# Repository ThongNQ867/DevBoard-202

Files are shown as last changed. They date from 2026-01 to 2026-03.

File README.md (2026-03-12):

# DevBoard202
This is a dev board that runs with the RP2040 but structured more simple than Pi Pico. The schematic is inspired by the document "Hardware design with RP2040", the PCB is made with the tutorial from @KaiPereira.
The reason I do this project is to understand more about how capacitors, resistors are used with components like MCU, oscillator, USB ports. Moreover, design a development board provide more control over how  I can use the MCU, in which I remove some functionalities from the Pi Pico to make this board simple and easier to use. 

Using instruction:
Using this development board is similar to any other development board. We can just plug wires to GPIO pins to use. The usage of GPIO pins can be find on the datasheet of Raspberry Pi Pico or the RP2040 itself. This dev board can be used with external power source, and to do so, we can wire a 5V power source to the VBus or VSYS pins.

While there is a tutorial from Blueprint, I think it is better to fact check stuffs again and get understand more clearly about how to set up the value for resistors and capacitors by myself from these 2 links:
RP2040 datasheet
https://pip-assets.raspberrypi.com/categories/814-rp2040/documents/RP-008371-DS-1-rp2040-datasheet.pdf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

Hardware design with rp2040
https://pip-assets.raspberrypi.com/categories/814-rp2040/documents/RP-008279-DS-1-hardware-design-with-rp2040.pdf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

Pi Pico Datasheet
https://pip-assets.raspberrypi.com/categories/610-raspberry-pi-pico/documents/RP-008307-DS-1-pico-datasheet.pdf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

Here is the result:
3D model: 

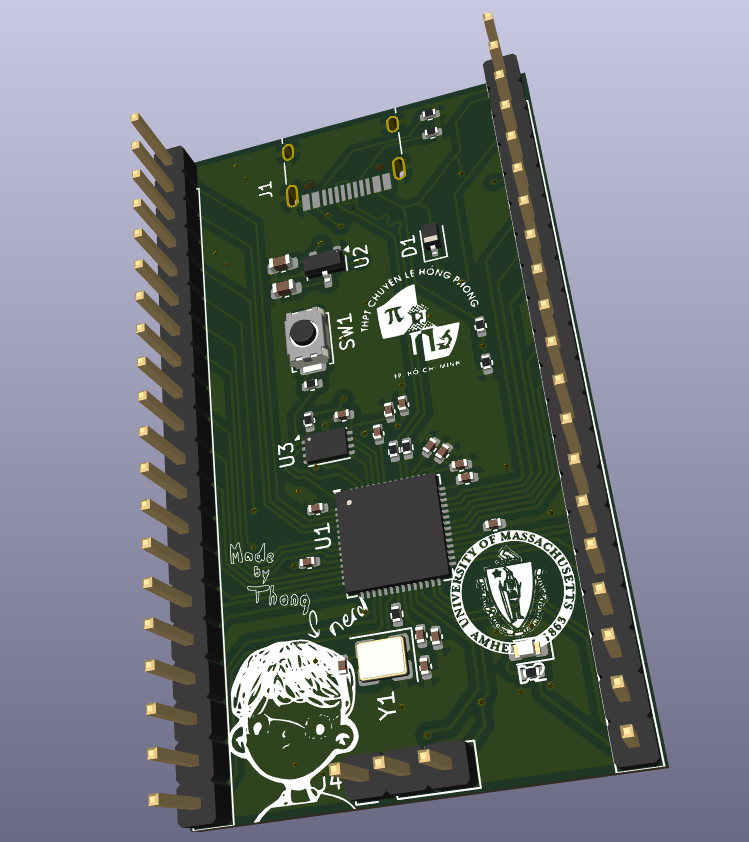
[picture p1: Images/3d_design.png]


Schematic: 

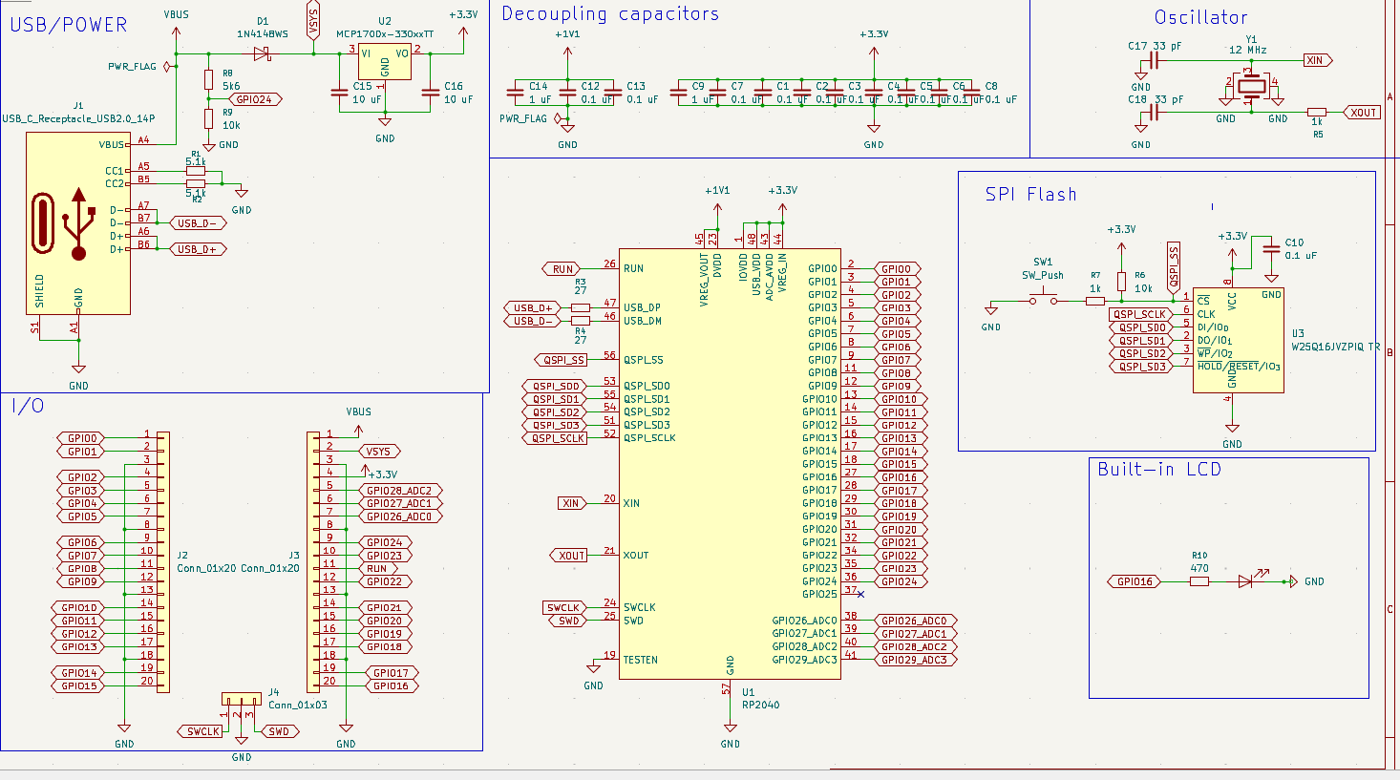
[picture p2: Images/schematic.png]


PCB: 

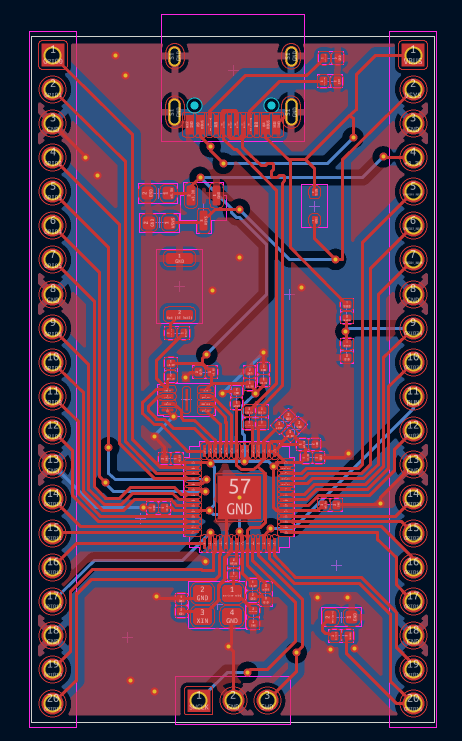
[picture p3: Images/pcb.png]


First, lets start of with setting up the decoupling capacitors. From the tutorial, it is recommended to used 1 capacitors per powerline so I just follow it. However, I found it a bit troublesome to actually know which pin is a powerline as I'm not very used to reading datasheets. Before this, I had always connect the pins to the capacitor (just as the datasheets often describe), making the schematic super hard to read. However, from the tutorial, I learnt that I can connect them seperately, making the schematic much more easier to read, and also solving the problem that the symbol of rp2040 on kicad doesnt shows all the power pins. 

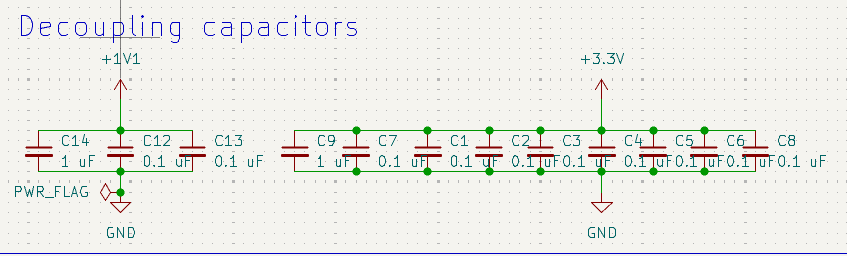
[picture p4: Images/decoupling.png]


Next is the powerline. Though it looks simple, it actually took me some time to actually figure out how the powerline, VSYS and VBUS works as I was trying to make my devboard be able to use an external power source. I added a VSYS pin which include the use of a Schottky diode between the VBUS and VSYS so that I can power it by an external power source. I found it quite challenging to understand how the USB host mode work but I think powering the external power source to the VBUS would probably be fine. Also because of powering externally to VSYS, I also pull VBUS down if its not connected to power source with 2 resistors to GND. After that, I also decided to wire the VBUS to a GPIO pin to detect if the board is using external power source

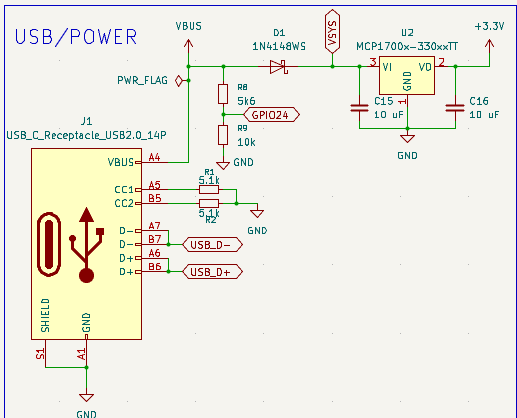
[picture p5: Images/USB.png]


SPI flash, built-in LED and oscillator is pretty straight forward, but I did learn so much on how to calculate the resistor for the oscillator.

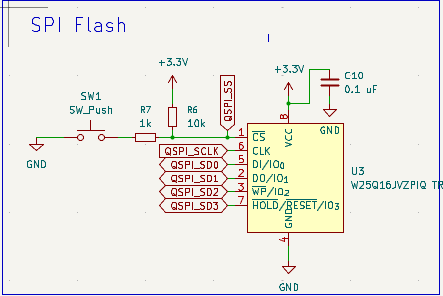
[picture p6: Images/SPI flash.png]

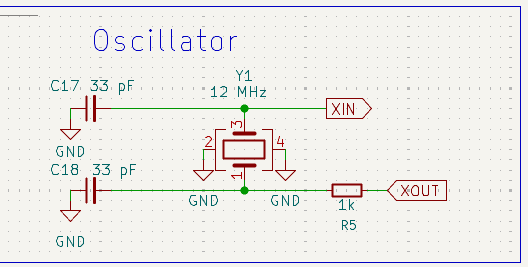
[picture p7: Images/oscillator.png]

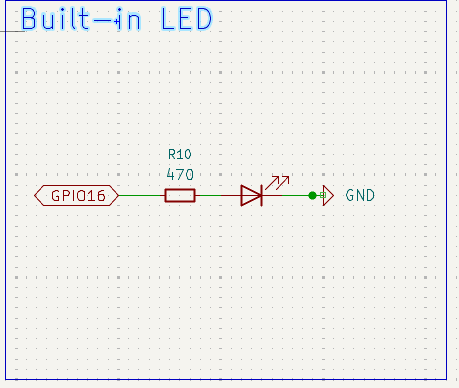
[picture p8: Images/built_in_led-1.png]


For me, PCB routing is the most problematic part of this project, partly because I'm new to KiCAD, partly because of the enormous diode (which I have changed to a more cost effective and 10 times smaller version). I started trying to make a PCB with the size of a Pi Pico but ended up increase the width to make the wiring easier 



This project has taught me a lot on how to use KiCAD and choose componets to print for my PCB. 

BOM: 
| Name | Comment | Designator | Footprint | JLCPCB Part # | Quantity | Links |
|---|---|---|---|---|---|---|
| CL10A106MA8NRNC | 10uF | C15,C16 | C_0603_1608Metric | C96446 | 2 | https://jlcpcb.com/partdetail/97651-CL10A106MA8NRNC/C96446 |
| CL05A105KA5NQNC | 1uF | C9,C14 | C_0402_1005Metric | C52923 | 2 | https://jlcpcb.com/partdetail/53938-CL05A105KA5NQNC/C52923 |
| MCP1700T-3302E/TT LDO | MCP1700x-330xxTT | U2 | SOT-23 | C39051 | 1 | https://jlcpcb.com/partdetail/MicrochipTech-MCP1700T_3302ETT/C39051 |
| 0402CG330J500NT | 33pF | C18,C17 | C_0402_1005Metric | C1562 | 2 | https://jlcpcb.com/partdetail/1914-0402CG330J500NT/C1562 |
| 0402WGF1001TCE | 1k | R7,R5 | R_0402_1005Metric | C11702 | 2 | https://jlcpcb.com/partdetail/12256-0402WGF1001TCE/C11702 |
| RCT0227RJLF | 27 | R3,R4 | R_0402_1005Metric | C174257 | 2 | https://jlcpcb.com/partdetail/HKR_Hong_Kong_Resistors-RCT0227RJLF/C174257 |
| 0402WGF5101TCE | 5.1k | R2,R1 | R_0402_1005Metric | C25905 | 2 | https://jlcpcb.com/partdetail/26648-0402WGF5101TCE/C25905 |
| X322512MSB4SI oscillator | 12MHz | Y1 | Crystal_SMD_3225-4Pin_3.2x2.5mm | C9002 | 1 | https://jlcpcb.com/partdetail/YXC_CrystalOscillators-X322512MSB4SI/C9002 |
| 0402WGF5601TCE | 5k6 | R8 | R_0402_1005Metric | C25908 | 1 | https://jlcpcb.com/partdetail/26651-0402WGF5601TCE/C25908 |
| 1N4148WS diode | 1N4148WS | D1 | D_SOD-323 | C2128 | 1 | https://jlcpcb.com/partdetail/2485-1N4148WS/C2128 |
| 0402WGF470JTCE | 470 | R10 | R_0402_1005Metric | C25118 | 1 | https://jlcpcb.com/partdetail/25861-0402WGF470JTCE/C25118 |
| RP2040 | RP2040 | U1 | QFN-56-1EP_7x7mm_P0.4mm_EP3.2x3.2mm | C2040 | 1 | https://jlcpcb.com/partdetail/RaspberryPi-RP2040/C2040 |
| CL05B104KO5NNNC | 100nF | C8,C7,C13,C5,C12,C1,C2,C6,C4,C10,C3 | C_0402_1005Metric | C1525 | 11 | https://jlcpcb.com/partdetail/1877-CL05B104KO5NNNC/C1525 |
| W25Q16JVUXIQ Flash | W25Q16JVZPIQTR | U3 | Winbond_USON-8-1EP_3x2mm_P0.5mm_EP0.2x1.6mm | C2843335 | 1 | https://jlcpcb.com/partdetail/WinbondElec-W25Q16JVUXIQ/C2843335 |
| KT-0603R LED | LED | D2 | LED_0603_1608Metric | C2286 | 1 | https://jlcpcb.com/partdetail/Hubei_KENTOElec-KT0603R/C2286 |
| 402WGF1002TC | 10k | R6,R9 | R_0402_1005Metric | C25744 | 2 | https://jlcpcb.com/partdetail/26487-0402WGF1002TCE/C25744 |
| TYPE-C-31-M-12 USB-C port | USB_C_Receptacle_USB2.0_14P | J1 | USB_C_Receptacle_HRO_TYPE-C-31-M-12 | C165948 | 1 | https://jlcpcb.com/partdetail/Korean_HropartsElec-TYPE_C_31_M12/C165948 |
| TS-1088-AR02016 | SW_Push | SW1 | SW_Push_SPST_NO_Alps_SKRK | C720477 | 1 | https://jlcpcb.com/partdetail/XUNPU-TS_1088AR02016/C720477 |

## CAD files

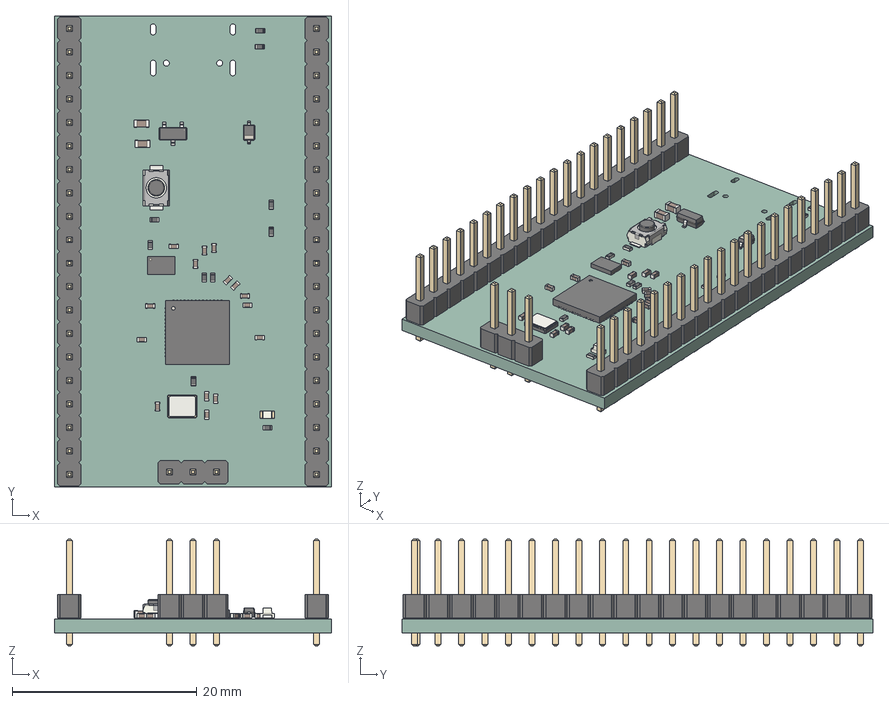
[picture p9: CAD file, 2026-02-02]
devboard202.step
30.0 x 51.0 x 11.5 mm
R_0402_1005Metric x 10
C_0402_1005Metric x 15
C_0603_1608Metric x 2
Winbond_USON-8-1EP_3x2mm_P0.5mm_EP0.2x1.6mm
D_SOD-323
SW_Push_SPST_NO_Alps_SKRK
Crystal_SMD_3225-4Pin_3.2x2.5mm
PinHeader_1x20_P2.54mm_Vertical x 2
SOT-23
QFN-56-1EP_7x7mm_P0.4mm_EP3.2x3.2mm
LED_0603_1608Metric
PinHeader_1x03_P2.54mm_Vertical
devboard202_PCB

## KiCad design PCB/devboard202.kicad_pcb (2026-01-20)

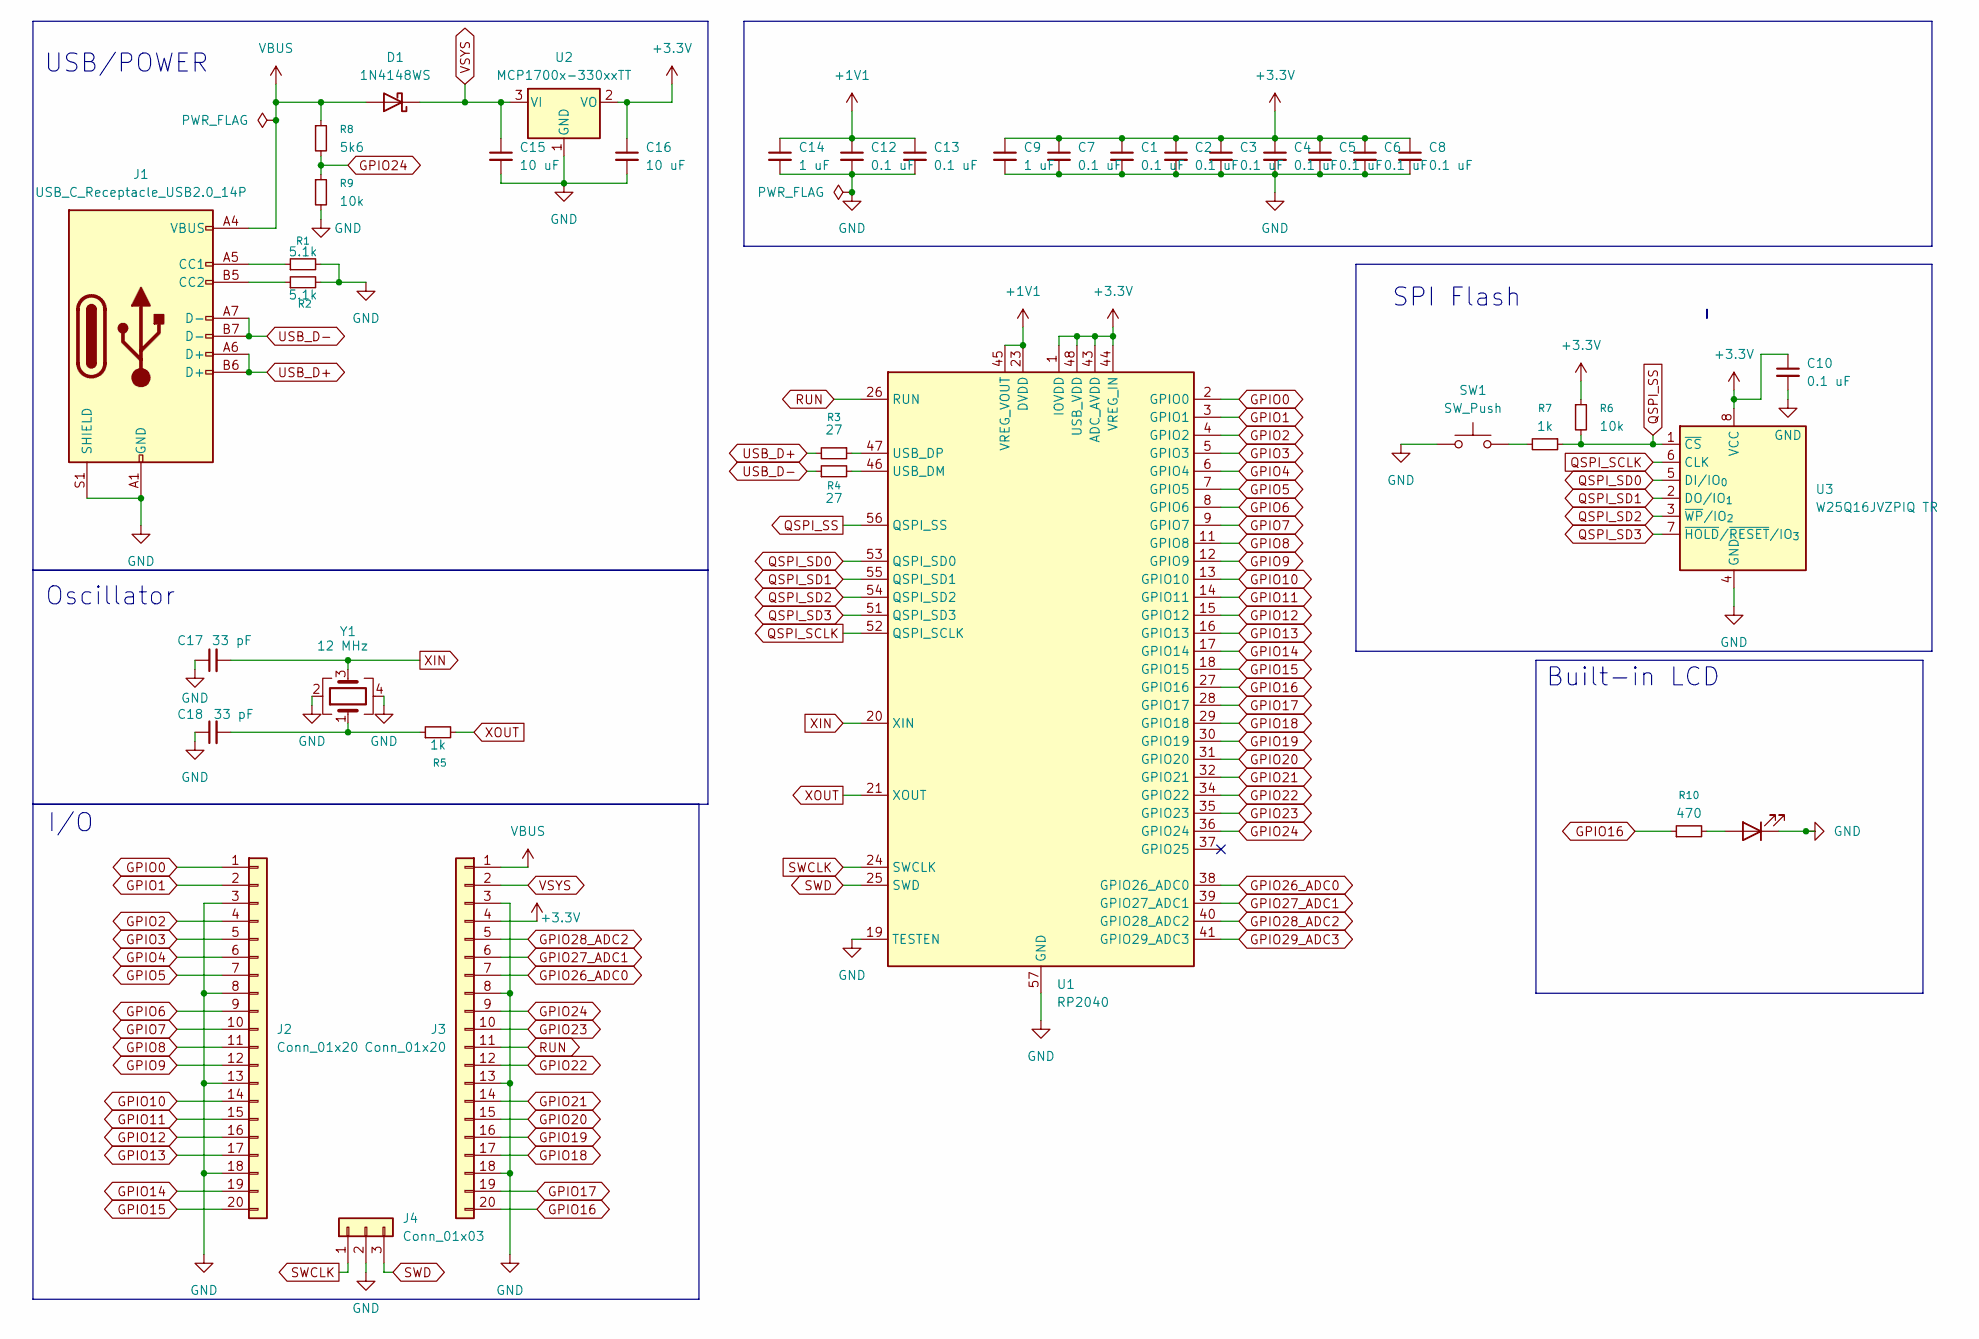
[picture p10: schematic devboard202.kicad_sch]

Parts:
C1, C2, C3, C4, C5, C6, C7, C8, C10, C12, C13: 0.1 uF; C_0402_1005Metric
C9, C14: 1 uF; C_0402_1005Metric
C15, C16: 10 uF; C_0603_1608Metric
C17, C18: 33 pF; C_0402_1005Metric
D1: 1N4148WS; D_SOD-323
D2: LED; LED_0402_1005Metric
J1: USB_C_Receptacle_USB2.0_14P; USB_C_Receptacle_HRO_TYPE-C-31-M-12
J2, J3: Conn_01x20; PinHeader_1x20_P2.54mm_Vertical
J4: Conn_01x03; PinHeader_1x03_P2.54mm_Vertical
R1, R2: 5.1k; R_0402_1005Metric
R3, R4: 27; R_0402_1005Metric
R5, R7: 1k; R_0402_1005Metric
R6, R9: 10k; R_0402_1005Metric
R8: 5k6; R_0402_1005Metric
R10: 470; R_0402_1005Metric
SW1: SW_Push; SW_Push_SPST_NO_Alps_SKRK
U1: RP2040; QFN-56-1EP_7x7mm_P0.4mm_EP3.2x3.2mm
U2: MCP1700x-330xxTT; SOT-23
U3: W25Q16JVZPIQ TR; Winbond_USON-8-1EP_3x2mm_P0.5mm_EP0.2x1.6mm
Y1: 12 MHz; Crystal_SMD_3225-4Pin_3.2x2.5mm

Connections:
+1V1: C12.1, C13.1, C14.1, U1.23 (DVDD), U1.45 (VREG_VOUT), U1.50 (DVDD)
+3.3V: C1.1, C2.1, C3.1, C4.1, C5.1, C6.1, C7.1, C8.1, C9.1, C10.1, C16.1, J3.4, R6.1, U1.1 (IOVDD), U1.10 (IOVDD), U1.22 (IOVDD), U1.33 (IOVDD), U1.42 (IOVDD), U1.43 (ADC_AVDD), U1.44 (VREG_IN), U1.48 (USB_VDD), U1.49 (IOVDD), U2.2 (VO), U3.8 (VCC)
GND: C1.2, C2.2, C3.2, C4.2, C5.2, C6.2, C7.2, C8.2, C9.2, C10.2, C12.2, C13.2, C14.2, C15.2, C16.2, C17.1, C18.1, D2.1 (K), J1.A1 (GND), J1.A12 (GND), J1.B1 (GND), J1.B12 (GND), J1.S1 (SHIELD), J2.3, J2.8, J2.13, J2.18, J3.3, J3.8, J3.13, J3.18, J4.2, R1.2, R2.2, R9.2, SW1.1, U1.19 (TESTEN), U1.57 (GND), U2.1 (GND), U3.4 (GND), Y1.2, Y1.4
GPIO0: J2.1, U1.2 (GPIO0)
GPIO1: J2.2, U1.3 (GPIO1)
GPIO2: J2.4, U1.4 (GPIO2)
GPIO3: J2.5, U1.5 (GPIO3)
GPIO4: J2.6, U1.6 (GPIO4)
GPIO5: J2.7, U1.7 (GPIO5)
GPIO6: J2.9, U1.8 (GPIO6)
GPIO7: J2.10, U1.9 (GPIO7)
GPIO8: J2.11, U1.11 (GPIO8)
GPIO9: J2.12, U1.12 (GPIO9)
GPIO10: J2.14, U1.13 (GPIO10)
GPIO11: J2.15, U1.14 (GPIO11)
GPIO12: J2.16, U1.15 (GPIO12)
GPIO13: J2.17, U1.16 (GPIO13)
GPIO14: J2.19, U1.17 (GPIO14)
GPIO15: J2.20, U1.18 (GPIO15)
GPIO16: J3.20, R10.1, U1.27 (GPIO16)
GPIO17: J3.19, U1.28 (GPIO17)
GPIO18: J3.17, U1.29 (GPIO18)
GPIO19: J3.16, U1.30 (GPIO19)
GPIO20: J3.15, U1.31 (GPIO20)
GPIO21: J3.14, U1.32 (GPIO21)
GPIO22: J3.12, U1.34 (GPIO22)
GPIO23: J3.10, U1.35 (GPIO23)
GPIO24: J3.9, R8.2, R9.1, U1.36 (GPIO24)
GPIO26_ADC0: J3.7, U1.38 (GPIO26_ADC0)
GPIO27_ADC1: J3.6, U1.39 (GPIO27_ADC1)
GPIO28_ADC2: J3.5, U1.40 (GPIO28_ADC2)
GPIO29_ADC3: U1.41 (GPIO29_ADC3)
unnamed: C18.2, R5.1, Y1.1
unnamed: D2.2 (A), R10.2
unnamed: J1.A5 (CC1), R1.1
unnamed: J1.B5 (CC2), R2.1
unnamed: R7.2, SW1.2
unnamed: R4.2, U1.46 (USB_DM)
unnamed: R3.1, U1.47 (USB_DP)
QSPI_SCLK: U1.52 (QSPI_SCLK), U3.6 (CLK)
QSPI_SD0: U1.53 (QSPI_SD0), U3.5 (DI/IO_{0})
QSPI_SD1: U1.55 (QSPI_SD1), U3.2 (DO/IO_{1})
QSPI_SD2: U1.54 (QSPI_SD2), U3.3 (~WP/IO_{2})
QSPI_SD3: U1.51 (QSPI_SD3), U3.7 (~HOLD/~RESET/IO_{3})
QSPI_SS: R6.2, R7.1, U1.56 (QSPI_SS), U3.1 (~CS)
RUN: J3.11, U1.26 (RUN)
SWCLK: J4.1, U1.24 (SWCLK)
SWD: J4.3, U1.25 (SWD)
USB_D+: J1.A6 (D+), J1.B6 (D+), R3.2
USB_D-: J1.A7 (D-), J1.B7 (D-), R4.1
VBUS: D1.2 (A), J1.A4 (VBUS), J1.A9 (VBUS), J1.B4 (VBUS), J1.B9 (VBUS), J3.1, R8.1
VSYS: C15.1, D1.1 (K), J3.2, U2.3 (VI)
XIN: C17.2, U1.20 (XIN), Y1.3
XOUT: R5.2, U1.21 (XOUT)

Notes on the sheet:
Oscillator
Built-in LCD
SPI Flash
USB/POWER
I/O

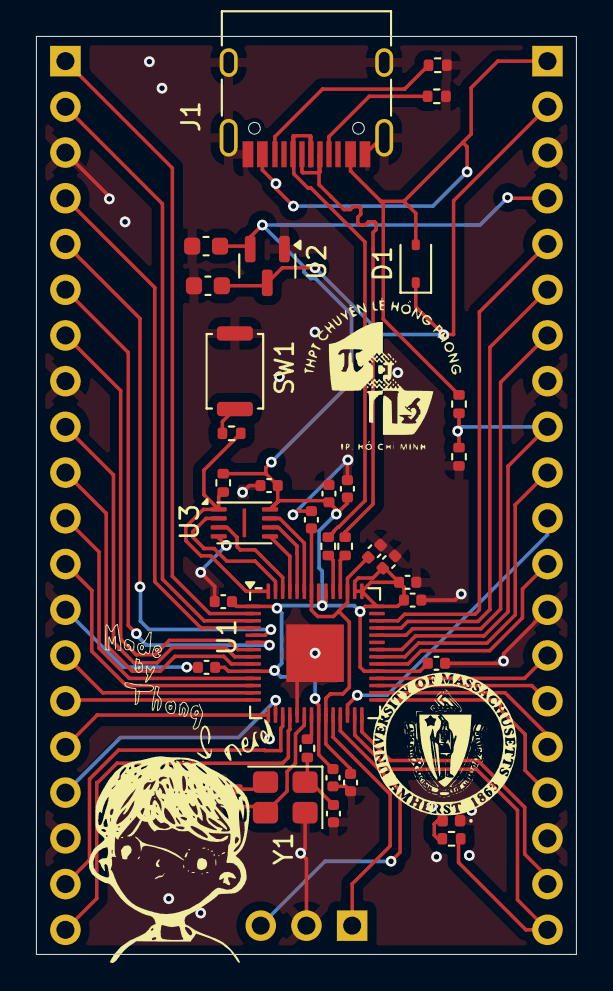
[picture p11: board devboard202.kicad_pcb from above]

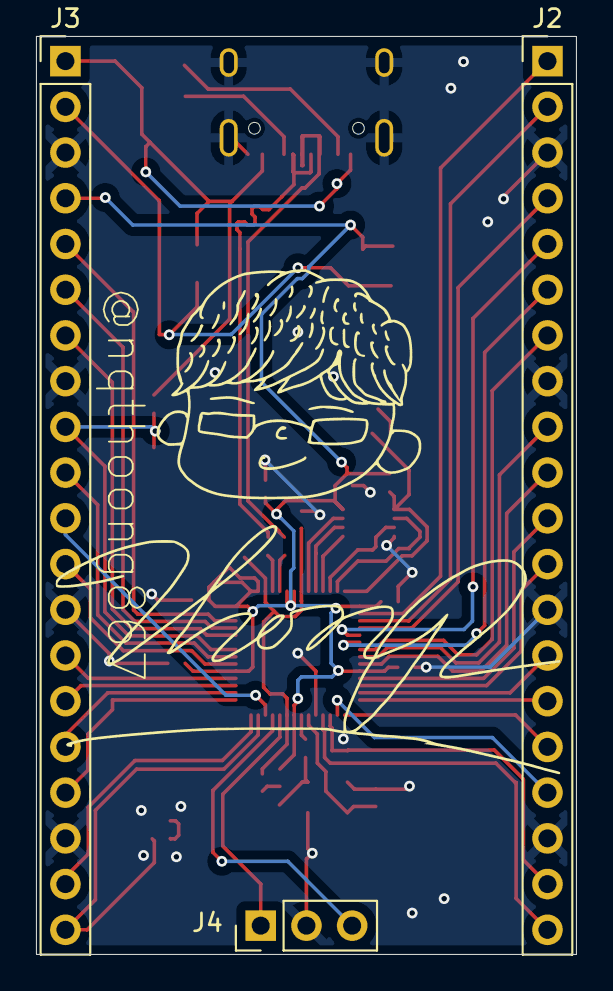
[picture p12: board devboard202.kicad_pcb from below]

Board: 2 copper layers, 30.0 x 51.0 mm, 38 parts (3 on the bottom side), 53 nets.

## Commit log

2026-01-20 ADD README
    [devboard202.csv, devboard202.kicad_pcb, devboard202.kicad_sch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]
2026-01-20 Update README
    Expanded project documentation with additional resources and insights on hardware design and PCB routing challenges.
2026-01-20 BOM Update
    Added a Bill of Materials (BOM) section
2026-02-02 update BOM
2026-02-02 update bom and .step file
    [bom.xls, devboard202.step]
2026-02-02 add BOM and .step file
    [bom.xls]
2026-02-02 addlink for BOM
    [bom.xls]
2026-02-20 Update the BOM
    [bom.xls, bom2.csv]
2026-02-20 gerber files update
2026-02-20 organize the files
    [bom2.csv, devboard202.csv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]
